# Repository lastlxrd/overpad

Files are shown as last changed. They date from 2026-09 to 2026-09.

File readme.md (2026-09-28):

# OVERPAD

A custom 12-key mechanical macropad with a rotary encoder, OLED display and RGB, powered by QMK.

<sub>[@lastlxrd](https://github.com/lastlxrd) · 2024</sub>

<p align="center">
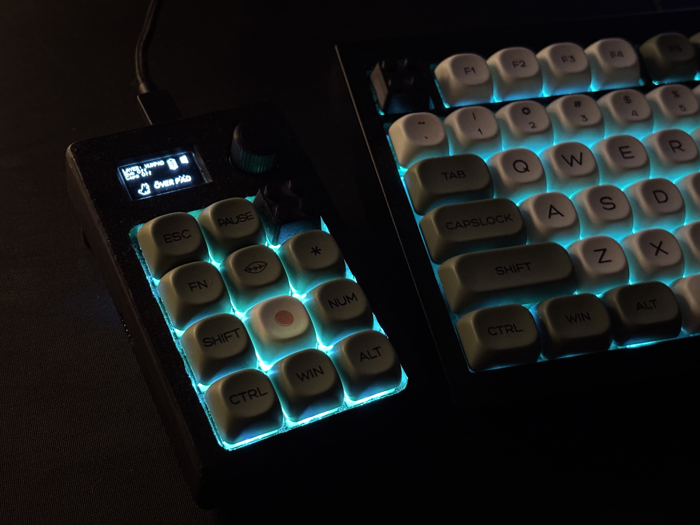
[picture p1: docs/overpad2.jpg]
  
</p>

<p align="center">
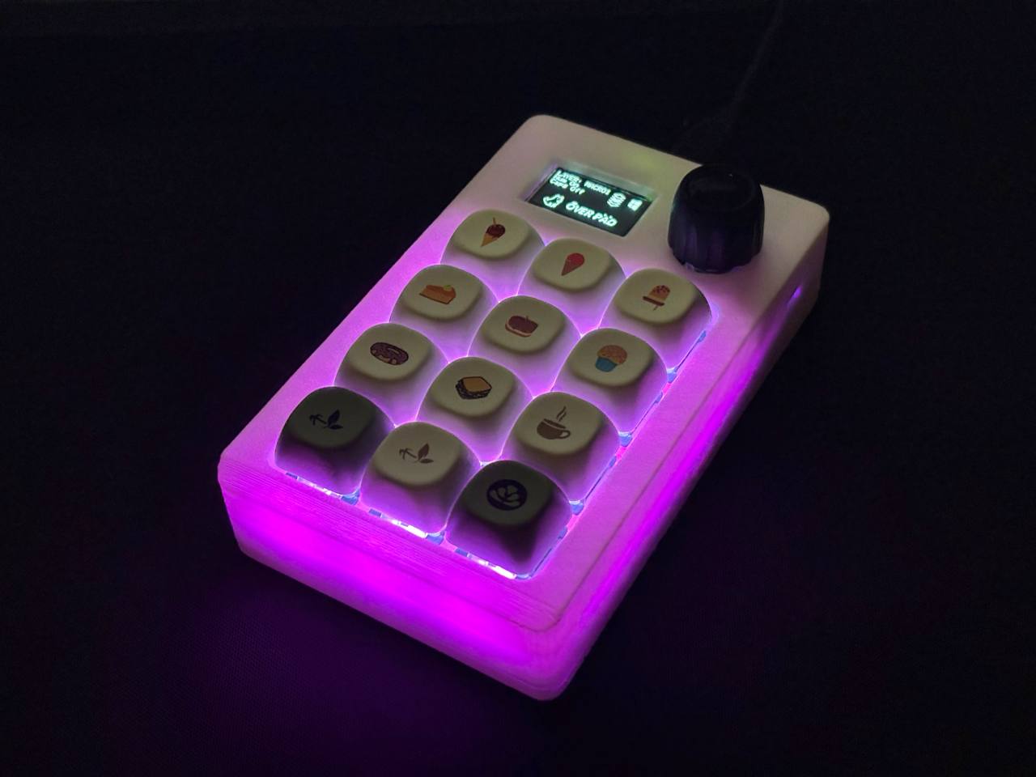
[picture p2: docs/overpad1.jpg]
  
</p>

<p align="center">
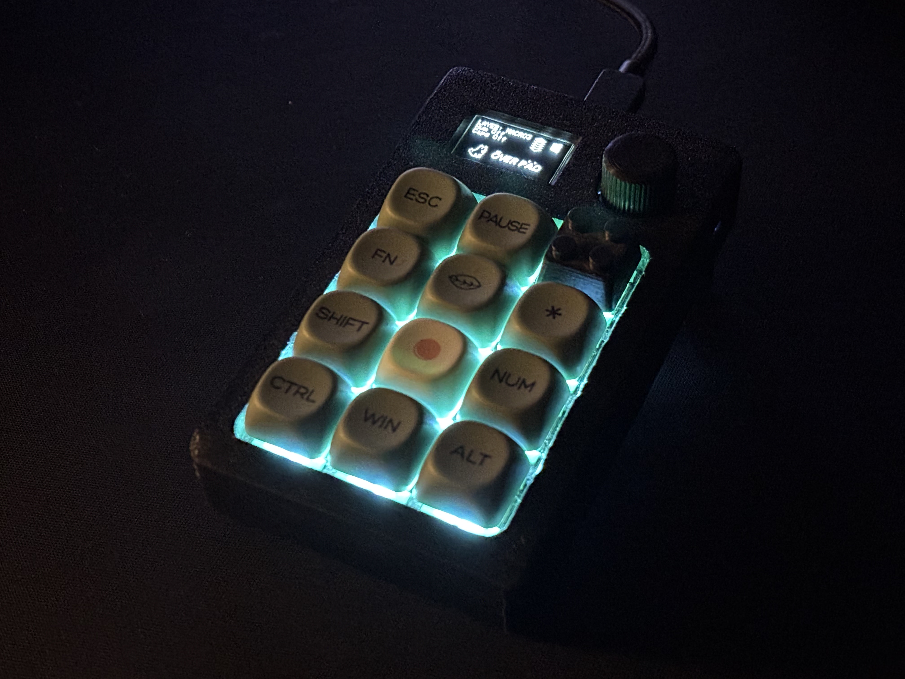
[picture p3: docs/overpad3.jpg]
  
</p>

OVERPAD is a compact programmable macropad built around the ATmega32U4 and QMK Firmware.

## Features

- 12 mechanical keys
- Rotary encoder with push button
- ATmega32U4 microcontroller
- 128×64 OLED display
- 12× WS2812 RGB LEDs
- QMK Firmware
- VIA support
- USB HID
- NKRO support
- Mouse keys and media controls
- Caterina bootloader

## Hardware

| Component | Description |
|---|---|
| MCU | ATmega32U4 |
| Keys | 12 mechanical keys |
| Encoder | Rotary encoder with push button |
| Display | 128×64 OLED |
| RGB | 12× WS2812 LEDs |
| Firmware | QMK |
| Configuration | VIA |
| Bootloader | Caterina |

## VIA configuration

OVERPAD supports VIA, allowing the keymap to be customized through a graphical interface without recompiling the firmware.

With VIA you can:

- Remap all 12 keys
- Configure multiple layers
- Assign media and system controls
- Create macros
- Change shortcuts and key functions
- Customize the layout without reflashing the firmware

The VIA definition is included in the repository:

[`keymaps/via/via.json`](keymaps/via/via.json)

### How to customize OVERPAD with VIA

1. Connect OVERPAD to your computer via USB.

2. Open VIA.

3. If OVERPAD is detected automatically, open the **Configure** tab and start remapping the keys.

4. If the keyboard is not detected automatically, enable the **Design** tab in VIA settings.

5. Load:

[`keymaps/via/via.json`](keymaps/via/via.json)

6. Return to the **Configure** tab.

7. Select any key on the OVERPAD layout and assign the desired function.

Changes are written directly to the keyboard and take effect immediately.

> OVERPAD must be running the VIA-enabled QMK firmware for VIA configuration to work.

## Firmware

OVERPAD firmware is based on QMK Firmware.

The repository contains the keyboard configuration files:

```text id="a8ulgl"
.
├── config.h
├── keyboard.json
├── rules.mk
├── LICENSE
├── NOTICE
├── LICENSE-ASSETS.md
├── docs/
│   ├── overpad1.jpg
│   ├── overpad2.jpg
│   └── overpad3.jpg
└── README.md
```

To use the keyboard definition inside a QMK installation, place it in:

```text id="mnyxy5"
qmk_firmware/keyboards/lastlxrd/overpad/
```

A QMK keymap can then be placed inside:

```text id="mnyxy5"
keymaps/default/ 
```

and compiled with:

```bash id="k6jx0a"
qmk compile -kb lastlxrd/overpad -km default
```

or flashed with:

```bash id="hzysyd"
qmk flash -kb lastlxrd/overpad -km default
```

> A `keymaps/default/keymap.c` file is required to build a complete firmware image.

## About

OVERPAD is an early custom hardware project developed in 2024.

The project combines PCB design, embedded firmware and mechanical keyboard hardware in a compact programmable controller.

## License

OVERPAD firmware and keyboard configuration files are licensed under the GNU General Public License v2.0 or later (`GPL-2.0-or-later`).

The firmware is based on QMK Firmware, which is distributed under the GNU General Public License.

Original project photographs and media located in `docs/` are not covered by the firmware license unless explicitly stated otherwise.

See `LICENSE`, `NOTICE` and `LICENSE-ASSETS.md` for details.

## Author

Designed and developed by [lastlxrd](https://github.com/lastlxrd).

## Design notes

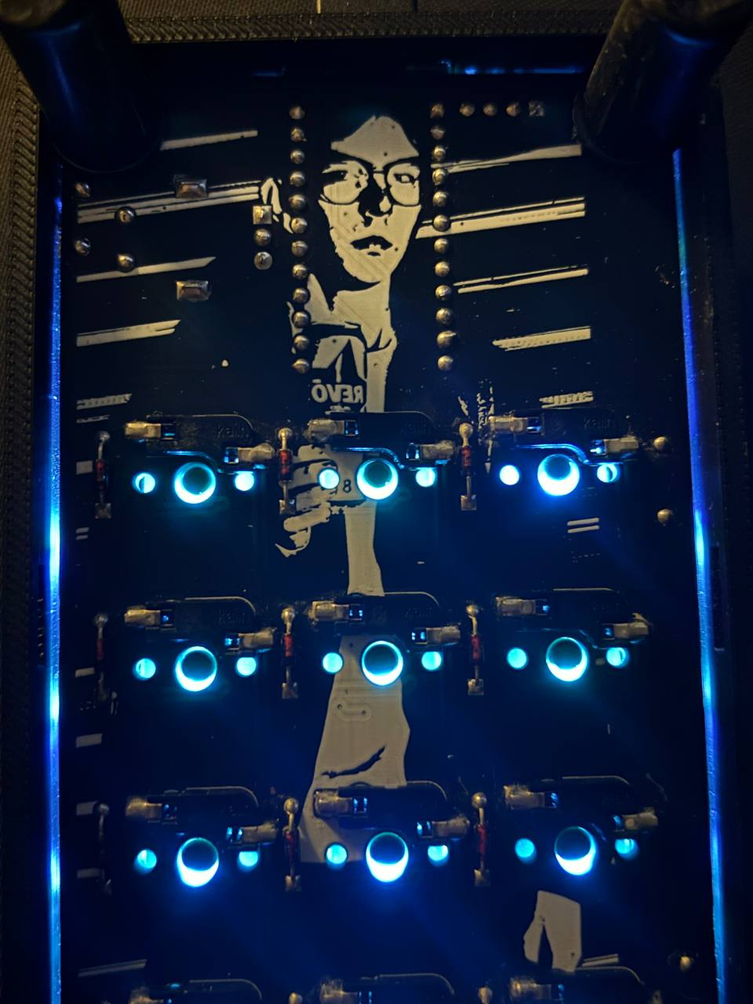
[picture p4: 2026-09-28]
docs/revoOVER.jpg

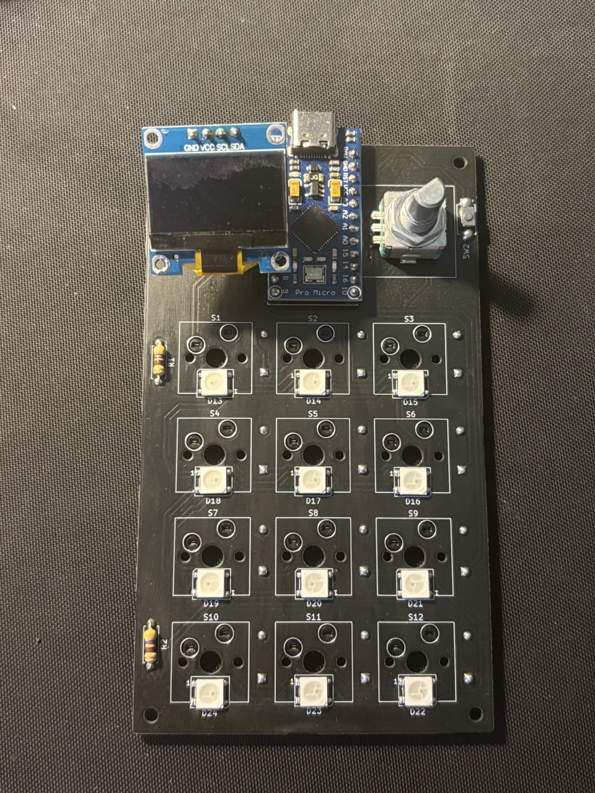
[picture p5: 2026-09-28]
docs/revopadPCB.jpg

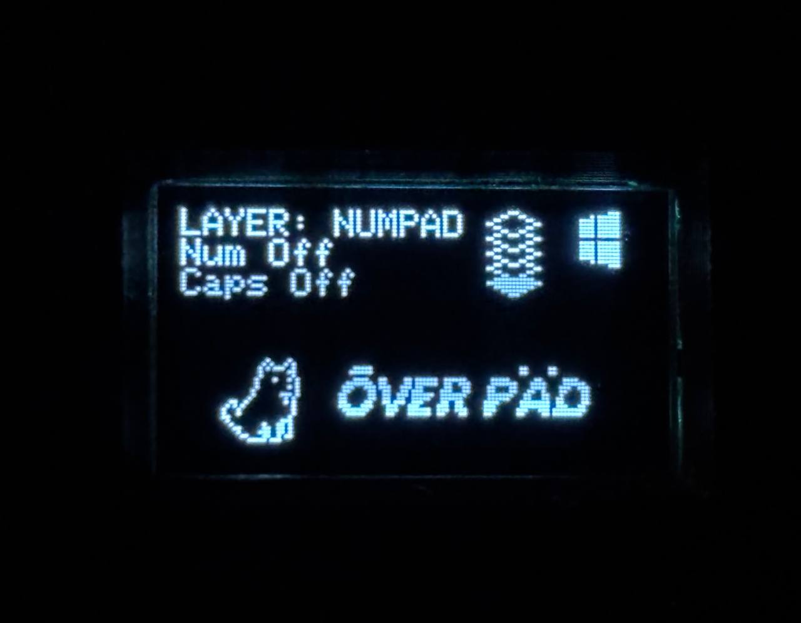
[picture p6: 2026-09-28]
docs/menuREVOMACROPAD.jpg

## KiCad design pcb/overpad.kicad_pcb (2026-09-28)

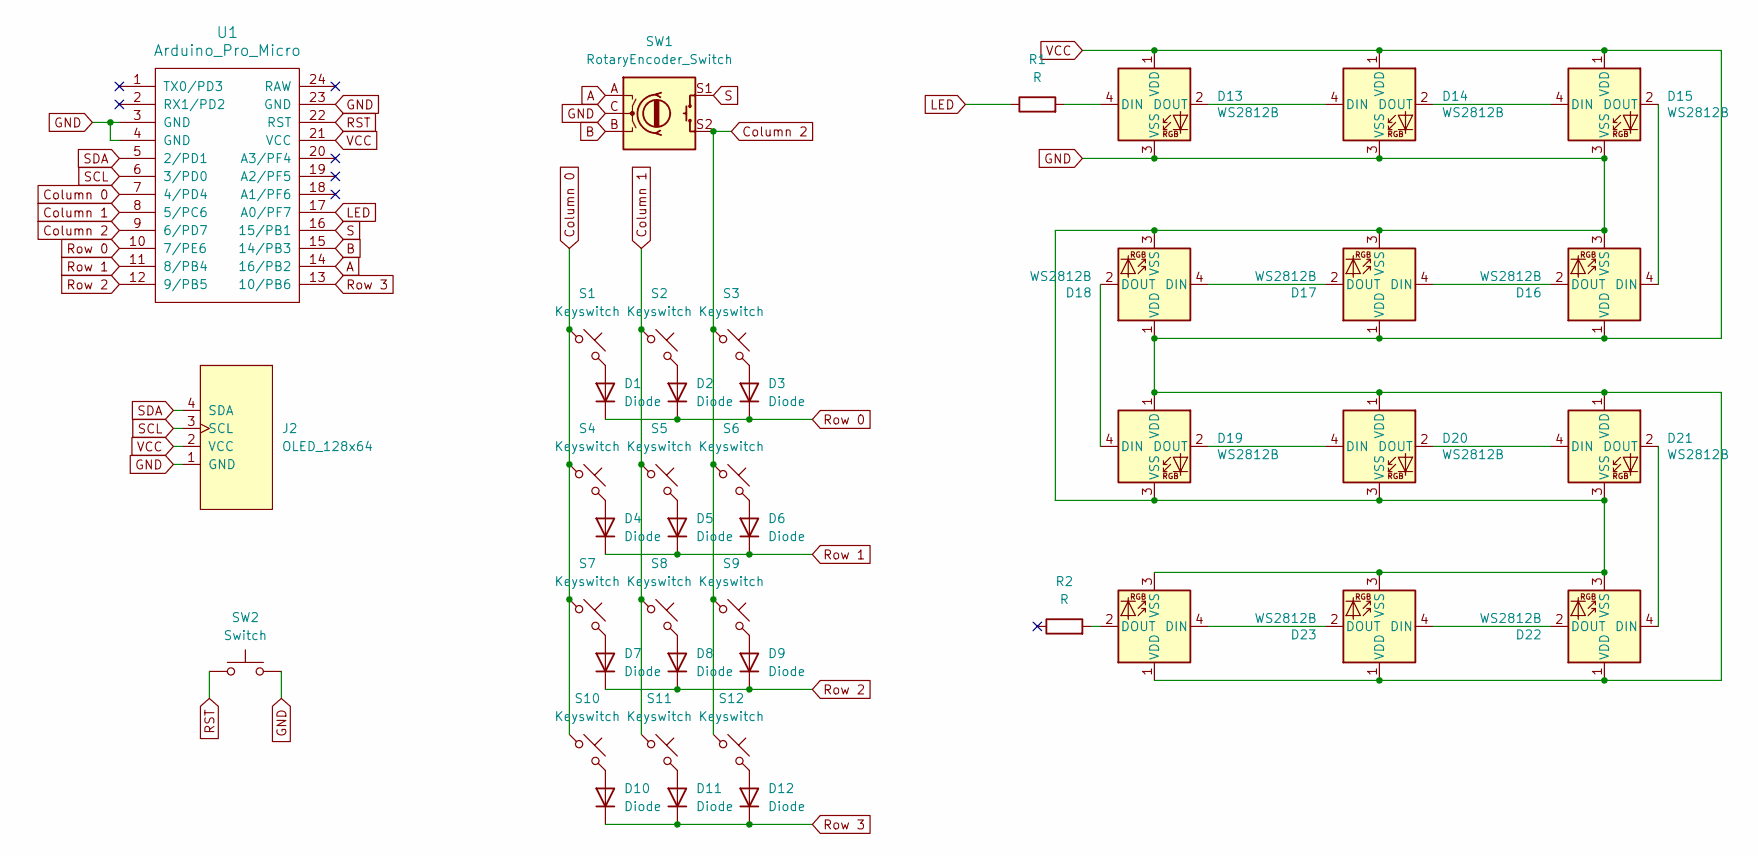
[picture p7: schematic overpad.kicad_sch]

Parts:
D1, D2, D3, D4, D5, D6, D7, D8, D9, D10, D11, D12: Diode; Diode_DO-35
D13, D14, D15, D16, D17, D18, D19, D20, D21, D22, D23, D24: WS2812B; LED_WS2812B_PLCC4_5.0x5.0mm_P3.2mm
J2: OLED_128x64
R1, R2: R; R_Axial_DIN0207_L6.3mm_D2.5mm_P7.62mm_Horizontal
S1, S2, S3, S4, S5, S6, S7, S8, S9, S10, S11, S12: Keyswitch; Hotswap_MX_Plated_1.00u
SW1: RotaryEncoder_Switch; Encoder_EC11_MX
SW2: Switch; Button_MJTP1243
U1: Arduino_Pro_Micro

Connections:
A: SW1.A, U1.14 (16/PB2)
B: SW1.B, U1.15 (14/PB3)
Column 0: S1.1, S4.1, S7.1, S10.1, U1.7 (4/PD4)
Column 1: S2.1, S5.1, S8.1, S11.1, U1.8 (5/PC6)
Column 2: S3.1, S6.1, S9.1, S12.1, SW1.S2, U1.9 (6/PD7)
GND: D13.3 (VSS), D14.3 (VSS), D15.3 (VSS), D16.3 (VSS), D17.3 (VSS), D18.3 (VSS), D19.3 (VSS), D20.3 (VSS), D21.3 (VSS), D22.3 (VSS), D23.3 (VSS), D24.3 (VSS), J2.1 (GND), SW1.C, SW2.2, U1.3 (GND), U1.4 (GND), U1.23 (GND)
LED: R1.1, U1.17 (A0/PF7)
unnamed: D1.2 (A), S1.2
unnamed: D2.2 (A), S2.2
unnamed: D3.2 (A), S3.2
unnamed: D4.2 (A), S4.2
unnamed: D5.2 (A), S5.2
unnamed: D6.2 (A), S6.2
unnamed: D7.2 (A), S7.2
unnamed: D8.2 (A), S8.2
unnamed: D9.2 (A), S9.2
unnamed: D10.2 (A), S10.2
unnamed: D11.2 (A), S11.2
unnamed: D12.2 (A), S12.2
unnamed: D13.4 (DIN), R1.2
unnamed: D13.2 (DOUT), D14.4 (DIN)
unnamed: D14.2 (DOUT), D15.4 (DIN)
unnamed: D15.2 (DOUT), D16.4 (DIN)
unnamed: D16.2 (DOUT), D17.4 (DIN)
unnamed: D17.2 (DOUT), D18.4 (DIN)
unnamed: D18.2 (DOUT), D19.4 (DIN)
unnamed: D19.2 (DOUT), D20.4 (DIN)
unnamed: D20.2 (DOUT), D21.4 (DIN)
unnamed: D21.2 (DOUT), D22.4 (DIN)
unnamed: D22.2 (DOUT), D23.4 (DIN)
unnamed: D23.2 (DOUT), D24.4 (DIN)
unnamed: D24.2 (DOUT), R2.2
RST: SW2.1, U1.22 (RST)
Row 0: D1.1 (K), D2.1 (K), D3.1 (K), U1.10 (7/PE6)
Row 1: D4.1 (K), D5.1 (K), D6.1 (K), U1.11 (8/PB4)
Row 2: D7.1 (K), D8.1 (K), D9.1 (K), U1.12 (9/PB5)
Row 3: D10.1 (K), D11.1 (K), D12.1 (K), U1.13 (10/PB6)
S: SW1.S1, U1.16 (15/PB1)
SCL: J2.3 (SCL), U1.6 (3/PD0)
SDA: J2.4 (SDA), U1.5 (2/PD1)
VCC: D13.1 (VDD), D14.1 (VDD), D15.1 (VDD), D16.1 (VDD), D17.1 (VDD), D18.1 (VDD), D19.1 (VDD), D20.1 (VDD), D21.1 (VDD), D22.1 (VDD), D23.1 (VDD), D24.1 (VDD), J2.2 (VCC), U1.21 (VCC)

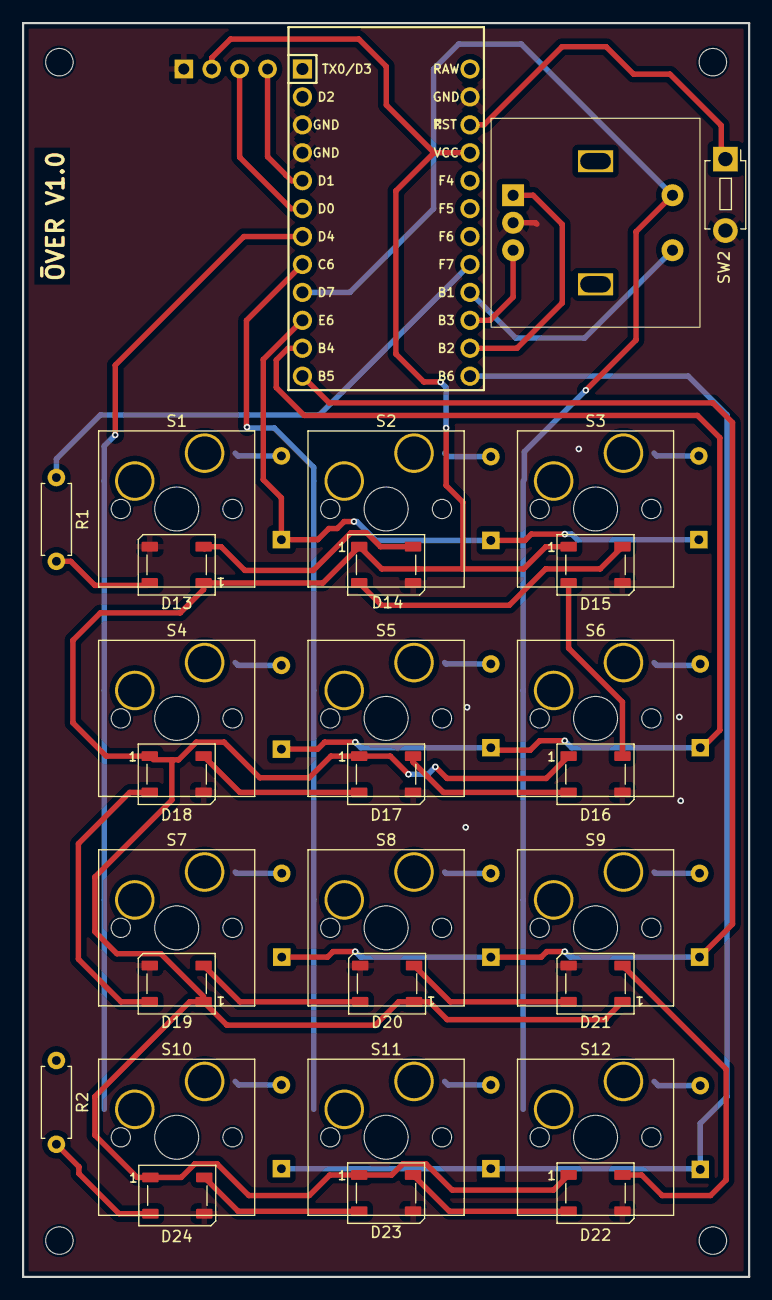
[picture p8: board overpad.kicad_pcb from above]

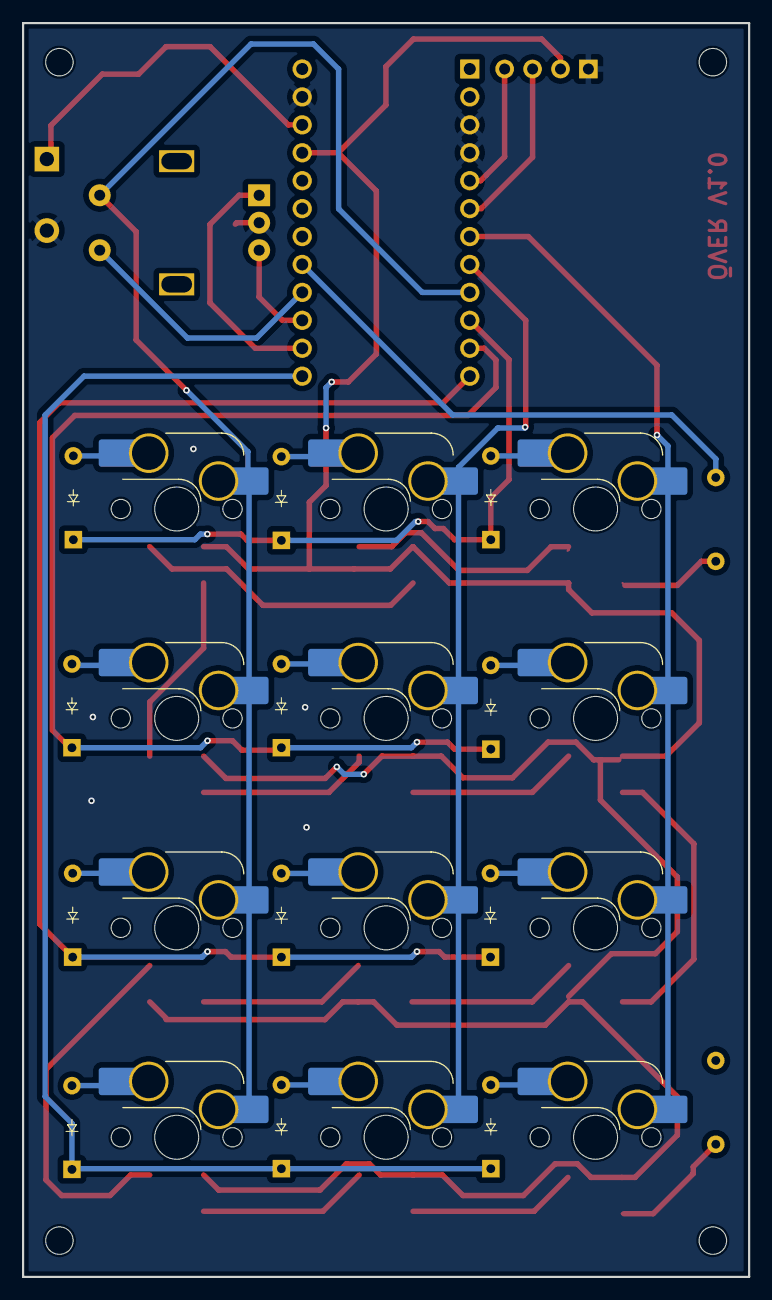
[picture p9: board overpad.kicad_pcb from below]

Board: 2 copper layers, 66.0 x 114.0 mm, 42 parts (12 on the bottom side), 41 nets.

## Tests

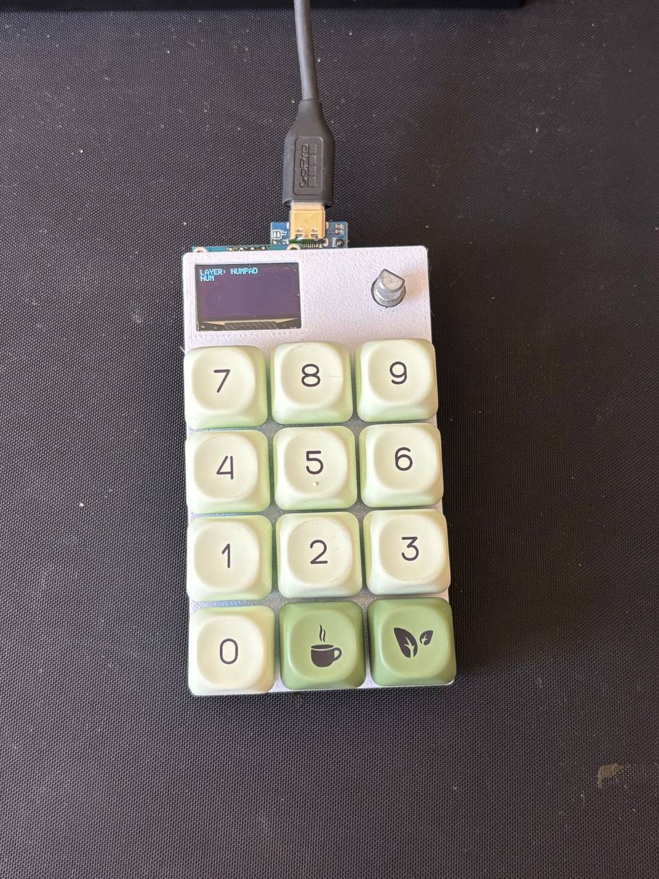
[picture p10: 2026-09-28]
docs/revopadi4_test.jpg

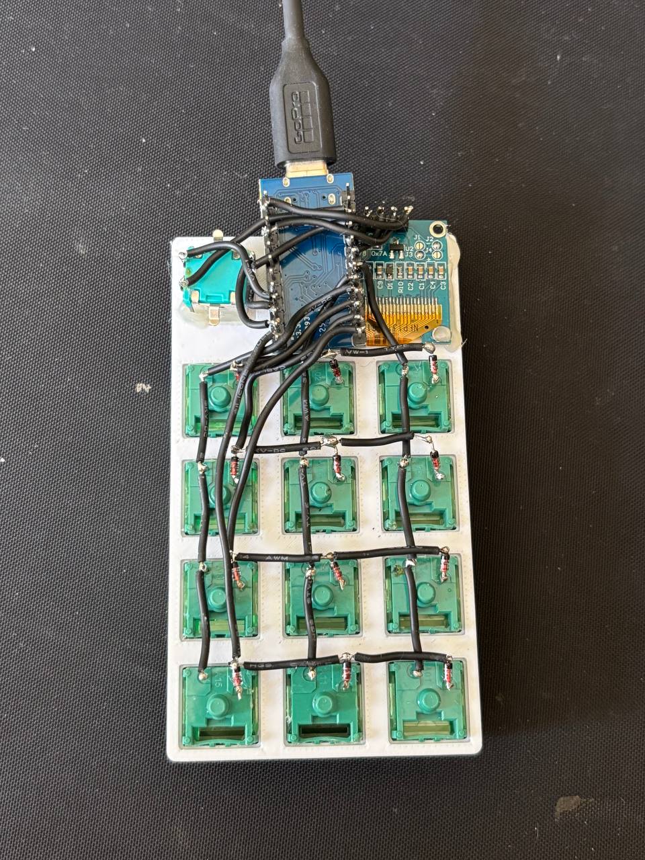
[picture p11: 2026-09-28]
docs/revopadTEST.jpg

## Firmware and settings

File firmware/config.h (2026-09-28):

#define ENCODER_A_PINS { B2 }
#define ENCODER_B_PINS { B3 }
#define ENCODER_DIRECTION_FLIP
#define OLED_DISPLAY_128X64
#define OLED_TIMEOUT 60000
#define OLED_FADE_OUT
#define OLED_FADE_OUT_INTERVAL 15
#define DYNAMIC_KEYMAP_LAYER_COUNT 5
#define DYNAMIC_KEYMAP_MACRO_COUNT 36
#define WS2812_DI_PIN F7

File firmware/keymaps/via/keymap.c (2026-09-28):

#include QMK_KEYBOARD_H
#include <stdbool.h>

enum sofle_layers {
    _Num,
    _Qwe,
    _Macro,
    _Macro1,
    _Macro2
};

const uint16_t PROGMEM keymaps[][MATRIX_ROWS][MATRIX_COLS] = {




    [_Num] = {
        { KC_NO,   KC_NO,   KC_MUTE },
        { KC_P7,   KC_P8,   KC_P9 },
        { KC_P4,   KC_P5,   KC_P6 },
        { KC_P1,   KC_P2,   KC_P3 },
        { KC_P0,   KC_ENT,  KC_NUM_LOCK }
    },
    [_Qwe] = {
        { KC_NO,    KC_NO,    KC_MUTE },
        { KC_Q,     KC_W,     KC_E },
        { KC_A,     KC_S,     KC_D },
        { KC_LSFT,  KC_Z,     KC_X },
        { KC_LCTL,  KC_LALT,    KC_SPC }
    },
    [_Macro] = {
        { KC_NO,     KC_NO,     KC_MUTE },
        { _______,   _______,   _______ },
        { _______,   _______,   _______ },
        { _______,   _______,   _______ },
        { _______,   _______,   _______ }
    },
    [_Macro1] = {
        { KC_NO,     KC_NO,     KC_MUTE },
        { _______,   _______,   _______ },
        { _______,   _______,   _______ },
        { _______,   _______,   _______ },
        { _______,   _______,    _______ }
    },
    [_Macro2] = {
        { KC_NO,     KC_NO,      KC_MUTE },
        { _______,   _______,   _______ },
        { _______,   _______,   _______ },
        { _______,   _______,   _______ },
        { _______,   _______,    _______ }
    }
};

#if defined(ENCODER_MAP_ENABLE)
const uint16_t PROGMEM encoder_map[][NUM_ENCODERS][NUM_DIRECTIONS] = {
    [0] = { ENCODER_CCW_CW(TO(4), TO(1)) },
    [1] = { ENCODER_CCW_CW(TO(0), TO(2)) },
    [2] = { ENCODER_CCW_CW(TO(1), TO(3)) },
    [3] = { ENCODER_CCW_CW(TO(2), TO(4)) },
    [4] = { ENCODER_CCW_CW(TO(3), TO(0)) }
};
#endif

#ifdef OLED_ENABLE

// OVER LOGO
static const char PROGMEM over_logo[2][72] = 
{
    {
        0,  0,128,192,200,108,108,108,236,204,128,  0,224,224,128,  0,  0,  0,128,224,224,  0,224,224, 96, 96, 96, 96,  0,  0,224,224, 32, 32, 96,224,192,  0,  0,  0,  0,  0,128,224, 96, 96, 96, 96,192,192,  0, 12, 12,  0,192,224,224,192,  0, 12, 12,  0,128,224,224, 96, 96,192,192,128,  0,  0,
    },
    {
        0, 30, 63,113, 96, 96, 96,112, 56, 31,  7,  0,  0, 15,127,112, 56, 14, 15,  3,112,127,127,111,102,102,  2,  0,112,127, 63,  7,  6, 62,126, 99,  1,  0,  0,  0,  0,120,127, 63, 14,  6,  6,  6,  3,  1, 96,120, 62, 31, 25, 24, 56,127,126,  0, 96,124,127,113, 96, 96, 96,112, 63, 15,  0,  0,
    }
};

// WINDOWS LOGO
static const char PROGMEM windows_logo[2][16] = 
{
    {
        0,  0,124,124,124,126,  0,126,126,126,127,127,127,  0,  0,  0,
    },
    {
        0,  0, 31, 31, 31, 63,  0, 63, 63, 63,127,127,127,  0,  0,  0,
    }
};

// LINUX OS LOGO
static const char PROGMEM linux_logo[2][16] = 
{
    {
        0,  0,  0,128,192,224,126, 91, 79, 91,254,192,  0,  0,  0,  0,
    },
    {
        0,  0, 48,123,127,120, 48, 32, 32, 48,120,127, 59,  0,  0,  0,
    }
};

// MAC OS LOGO
static const char PROGMEM mac_logo[2][16] = 
{
    {
        0,  0,  0,224,240,240,240,224,236,238,247,243,112, 32,  0,  0,
    },
    {
        0,  0,  0, 15, 31, 63,127,127,127,127,127, 63, 30, 12,  0,  0,
    }
};

// ANDROID OS LOGO
static const char PROGMEM android_logo[2][16] = 
{
    {
        0,  0,192,  0,220,215,222,222,222,215,220,  0,192,  0,  0,  0,
    },
    {
        0,  0,  3,  0, 15,127, 15, 15, 15,127, 15,  0,  3,  0,  0,  0,
    }
};

/* LAYERS LOGO */
static const char PROGMEM layer1[3][24] = 
{
    {
        136,136, 84, 84, 34, 34, 65, 65, 65, 34, 34, 84, 84,136,136
    },
    {
        136,136, 85, 85, 34, 34, 68, 68, 68, 34, 34, 85, 85,136,136
    },
    {
        8,  8, 29, 29, 62, 62,124,124,124, 62, 62, 29, 29,  8,  8
    }
};

static const char PROGMEM layer2[3][24] = 
{
    {
        136,136, 84, 84, 34, 34, 65, 65, 65, 34, 34, 84, 84,136,136
    },
    {
        136,136,213,213,226,226,196,196,196,226,226,213,213,136,136
    },
    {
        8,  8, 21, 21, 35, 35, 71, 71, 71, 35, 35, 21, 21,  8,  8
    }

};

static const char PROGMEM layer3[3][24] = 
{
    {
        136,136, 84, 84, 34, 34, 65, 65, 65, 34, 34, 84, 84,136,136
    },
    {
        136,136, 93, 93, 62, 62,124,124,124, 62, 62, 93, 93,136,136
    },
    {
        8,  8, 21, 21, 34, 34, 68, 68, 68, 34, 34, 21, 21,  8,  8
    }
};

static const char PROGMEM layer4[3][24] = 
{
    {
        136,136,212,212,226,226,193,193,193,226,226,212,212,136,136
    },
    {
        136,136, 85, 85, 35, 35, 71, 71, 71, 35, 35, 85, 85,136,136
    },
    {
        8,  8, 21, 21, 34, 34, 68, 68, 68, 34, 34, 21, 21,  8,  8
    }
};

static const char PROGMEM layer5[3][24] = 
{
    {
        136,136, 92, 92, 62, 62,127,127,127, 62, 62, 92, 92,136,136
    },
    {
        136,136, 85, 85, 34, 34, 68, 68, 68, 34, 34, 85, 85,136,136
    },
    {
        8,  8, 21, 21, 34, 34, 68, 68, 68, 34, 34, 21, 21,  8,  8
    }
};


/* KEYBOARD PET START */

/* settings */
#define MIN_WALK_SPEED 10
#define MIN_RUN_SPEED 30

/* advanced settings */
#define LUNA_FRAME_DURATION 230 // how long each frame lasts in ms
#define LUNA_SIZE 32 // number of bytes in array. This is how many pixels wide your image is. max is 1024 but would apply if line wrapping and not segmeting image and on 128x64 size screen, 512 is max on 128x32.

/* Setup Variables */
uint8_t current_frame = 0;
bool isSneaking = false;
bool isJumping = false;
bool showedJump = true;
int jump_height = 0;

// Loop to create line by line rendering for Horizontal display
// Input is oled_render_image(how many rows tall, how many pixels wide, what to render, X pos, Y pos, Frame offset)
	void oled_render_image(int lines, int px, const char render_line[][px], int X_pos, int Y_pos, int frame) {
	for (uint8_t i = 0; i <= (lines-1); i++){ 
            oled_set_cursor(X_pos, Y_pos + i);
			oled_write_raw_P(render_line[i + frame], px);
		}
	}
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
